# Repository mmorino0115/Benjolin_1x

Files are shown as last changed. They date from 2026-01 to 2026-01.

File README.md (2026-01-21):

# Benjolin_1x
Benjolin_1x KiCAD data. I designed this PCB based on the schematics of forestcaver's Benjolin 1.6. Then added some additional ideas from Jolin Lab's BE2N. I am really grateful to Rob Hordijk, who designed the original Benjolin. Following the original Benjolin design intent, this PCB is for personal, non-commercial use only.

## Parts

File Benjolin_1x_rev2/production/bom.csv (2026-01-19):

Designator | Footprint | Quantity | Value | LCSC Part #
C1, C2 | CP_Elec_5x4.5 | 2 | 47u
C10, C11, C12, C13, C14, C15, C16, C18, C19, C20, C21, C22, C23, C24, C25, C26, C28, C3, C4, C6, C7, C8, C9 | 0603 | 23 | 100n
C17, C5 | CP_Elec_4x5.4 | 2 | 10u
C27, C38 | 0603 | 2 | 1n
C29, C36, C37, C39 | 0603 | 4 | 560p
C30, C33, C34 | 0603 | 3 | 220p
C31, C32, C35 | 0603 | 3 | 18p
D1, D2, D6 | SOD-123 | 3 | 1N5819 | 1N5819
D10, D11, D18, D19, D22, D23, D24, D25, D26, D7, D8 | D_SOD-123F | 11 | 1N4148W-7
D12, D13, D14 | D_MiniMELF_Handsoldering | 3 | D_Zener 5V6
D15, D16, D17, D28, D5 | LED_D3.0mm | 5 | LED
D20, D21, D3, D9 | D_SMA | 4 | D_Schottky
D27, D4 | D_SMA_Handsoldering | 2 | 1n4004
FB1, FB2 | 0603 | 2 | FerriteBead
IC10 | SOT-89-3 | 1 | lm79l09
IC2 | TO-252-3 | 1 | lm78l09
J1, J10, J11, J12, J13, J14, J15, J16, J17, J2, J3, J35, J4, J5, J6, J7, J8, J9 | AudioJack_3.5mm | 18 | PJ301
JP1 | IDC-Header_2x05_P2.54mm_Vertical | 1 | M05X2PTH
POT1, POT10, POT11, POT12, POT13, POT14, POT15, POT2, POT3, POT4, POT5, POT7, POT8, POT9 | Potentiometer_Alps_RK09K_Single_Vertical | 14 | 10k
Q1, Q2, Q3, Q4, Q5, Q6 | SOT-23-3 | 6 | 2n3904
R1, R176, R18, R23, R27, R28, R29, R30, R32, R33, R49, R67, R71, R82, R86, R88 | 0603 | 16 | 10k
R10, R15, R20, R21, R22, R31, R34, R48, R52, R53, R54, R63, R65, R68, R76 | 0603 | 15 | 100k
R11 | 0603 | 1 | 62k
R12, R13, R26, R4, R41, R45, R47, R5, R51, R56, R57, R6, R66, R69, R7, R74, R8 | 0603 | 17 | 30k
R14, R16, R17, R171, R19, R24, R25, R35, R36, R37, R38, R43, R46, R77, R79, R83, R84, R87, R89, R9 | 0603 | 20 | 1k
R175 | 0603 | 1 | 7.5k
R179 | 0603 | 1 | 47k
R2, R3, R40, R59, R73 | 0603 | 5 | 15k
R39, R44, R55, R70, R72, R75, R80, R81, R85 | 0603 | 9 | 51k
R42, R58, R60, R78 | 0603 | 4 | 510
R50 | 0603 | 1 | 470k
R61 | 0603 | 1 | 20k
R62 | 0603 | 1 | 150k
R64 | 0603 | 1 | 1.5k
SW1, SW2, SW3 | 2MS3T1B3M2QES | 3 | submini-2T
U1, U5, U6 | TSSOP-14_4.4x5mm_P0.65mm | 3 | TL074
U10 | SOT-23-5 | 1 | LM321
U2, U8, U9 | TSSOP-8_4.4x3mm_P0.65mm | 3 | TL072
U3 | SOIC-16_3.9x9.9mm_P1.27mm | 1 | SSI2164_Split
U4 | SOIC-16_3.9x9.9mm_P1.27mm | 1 | 4021
V9 | PerkinElmer_VTL5C | 1 | VTL5C

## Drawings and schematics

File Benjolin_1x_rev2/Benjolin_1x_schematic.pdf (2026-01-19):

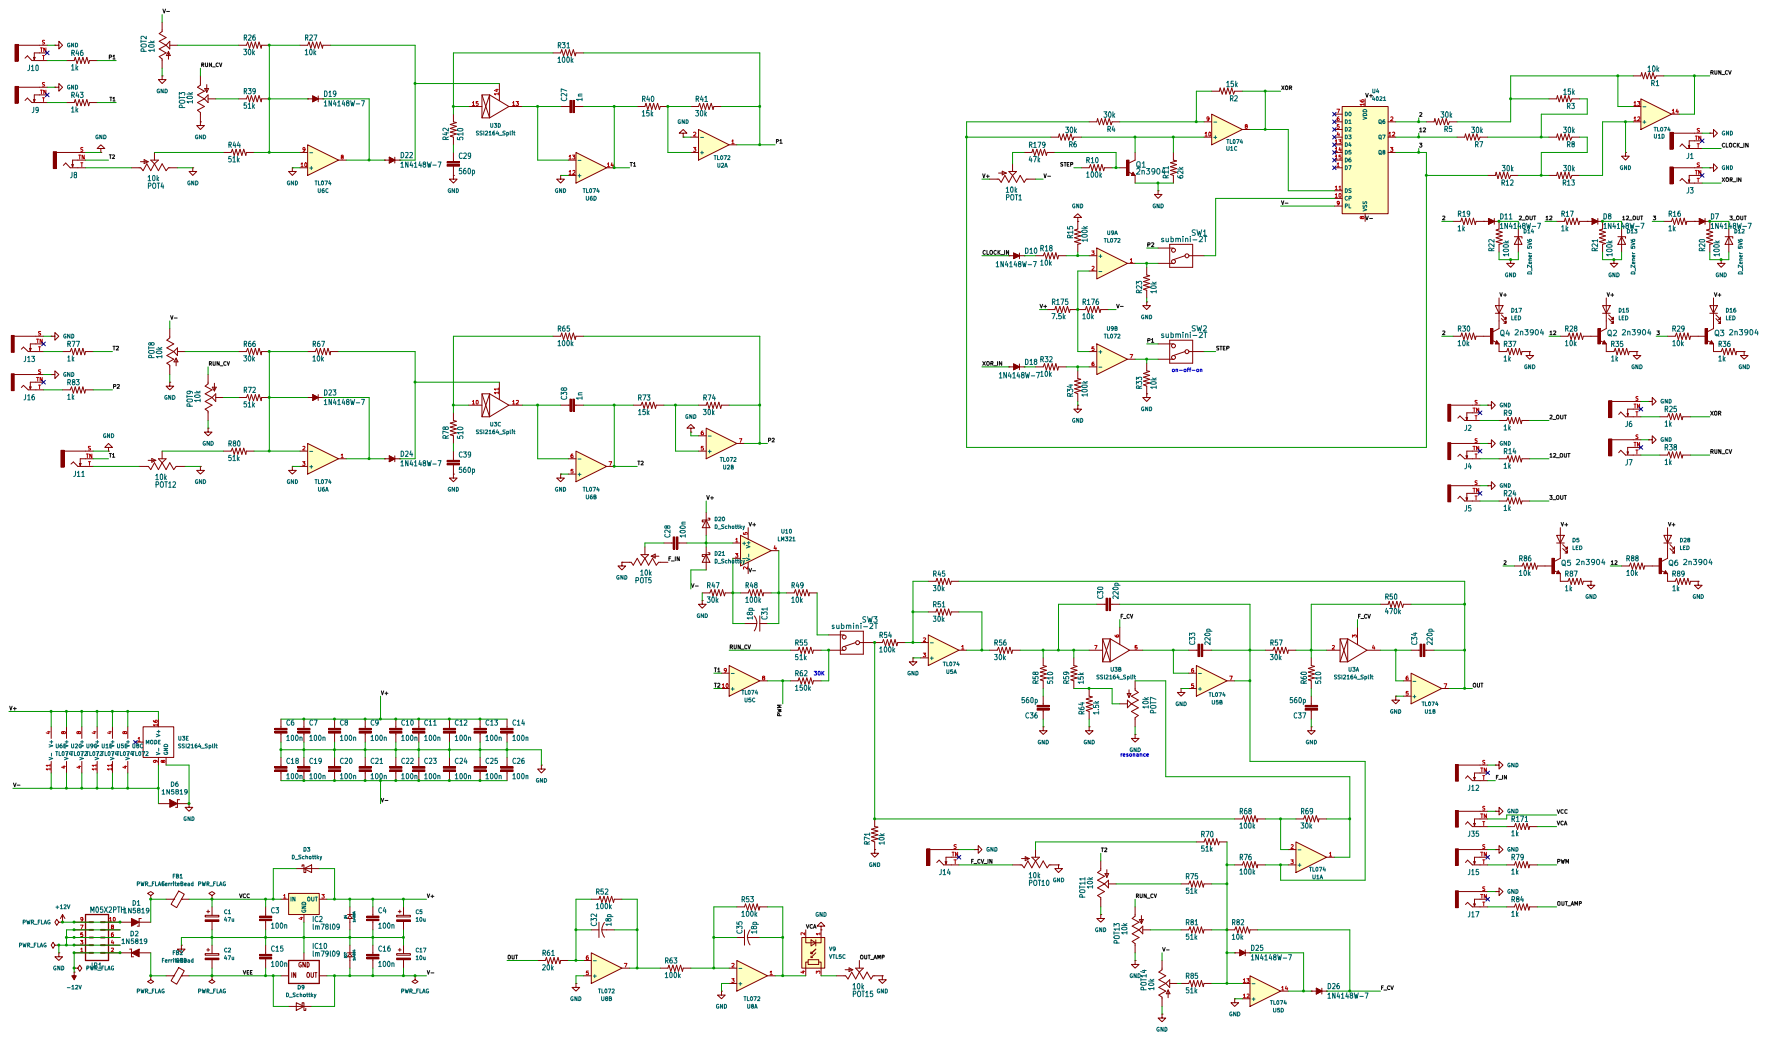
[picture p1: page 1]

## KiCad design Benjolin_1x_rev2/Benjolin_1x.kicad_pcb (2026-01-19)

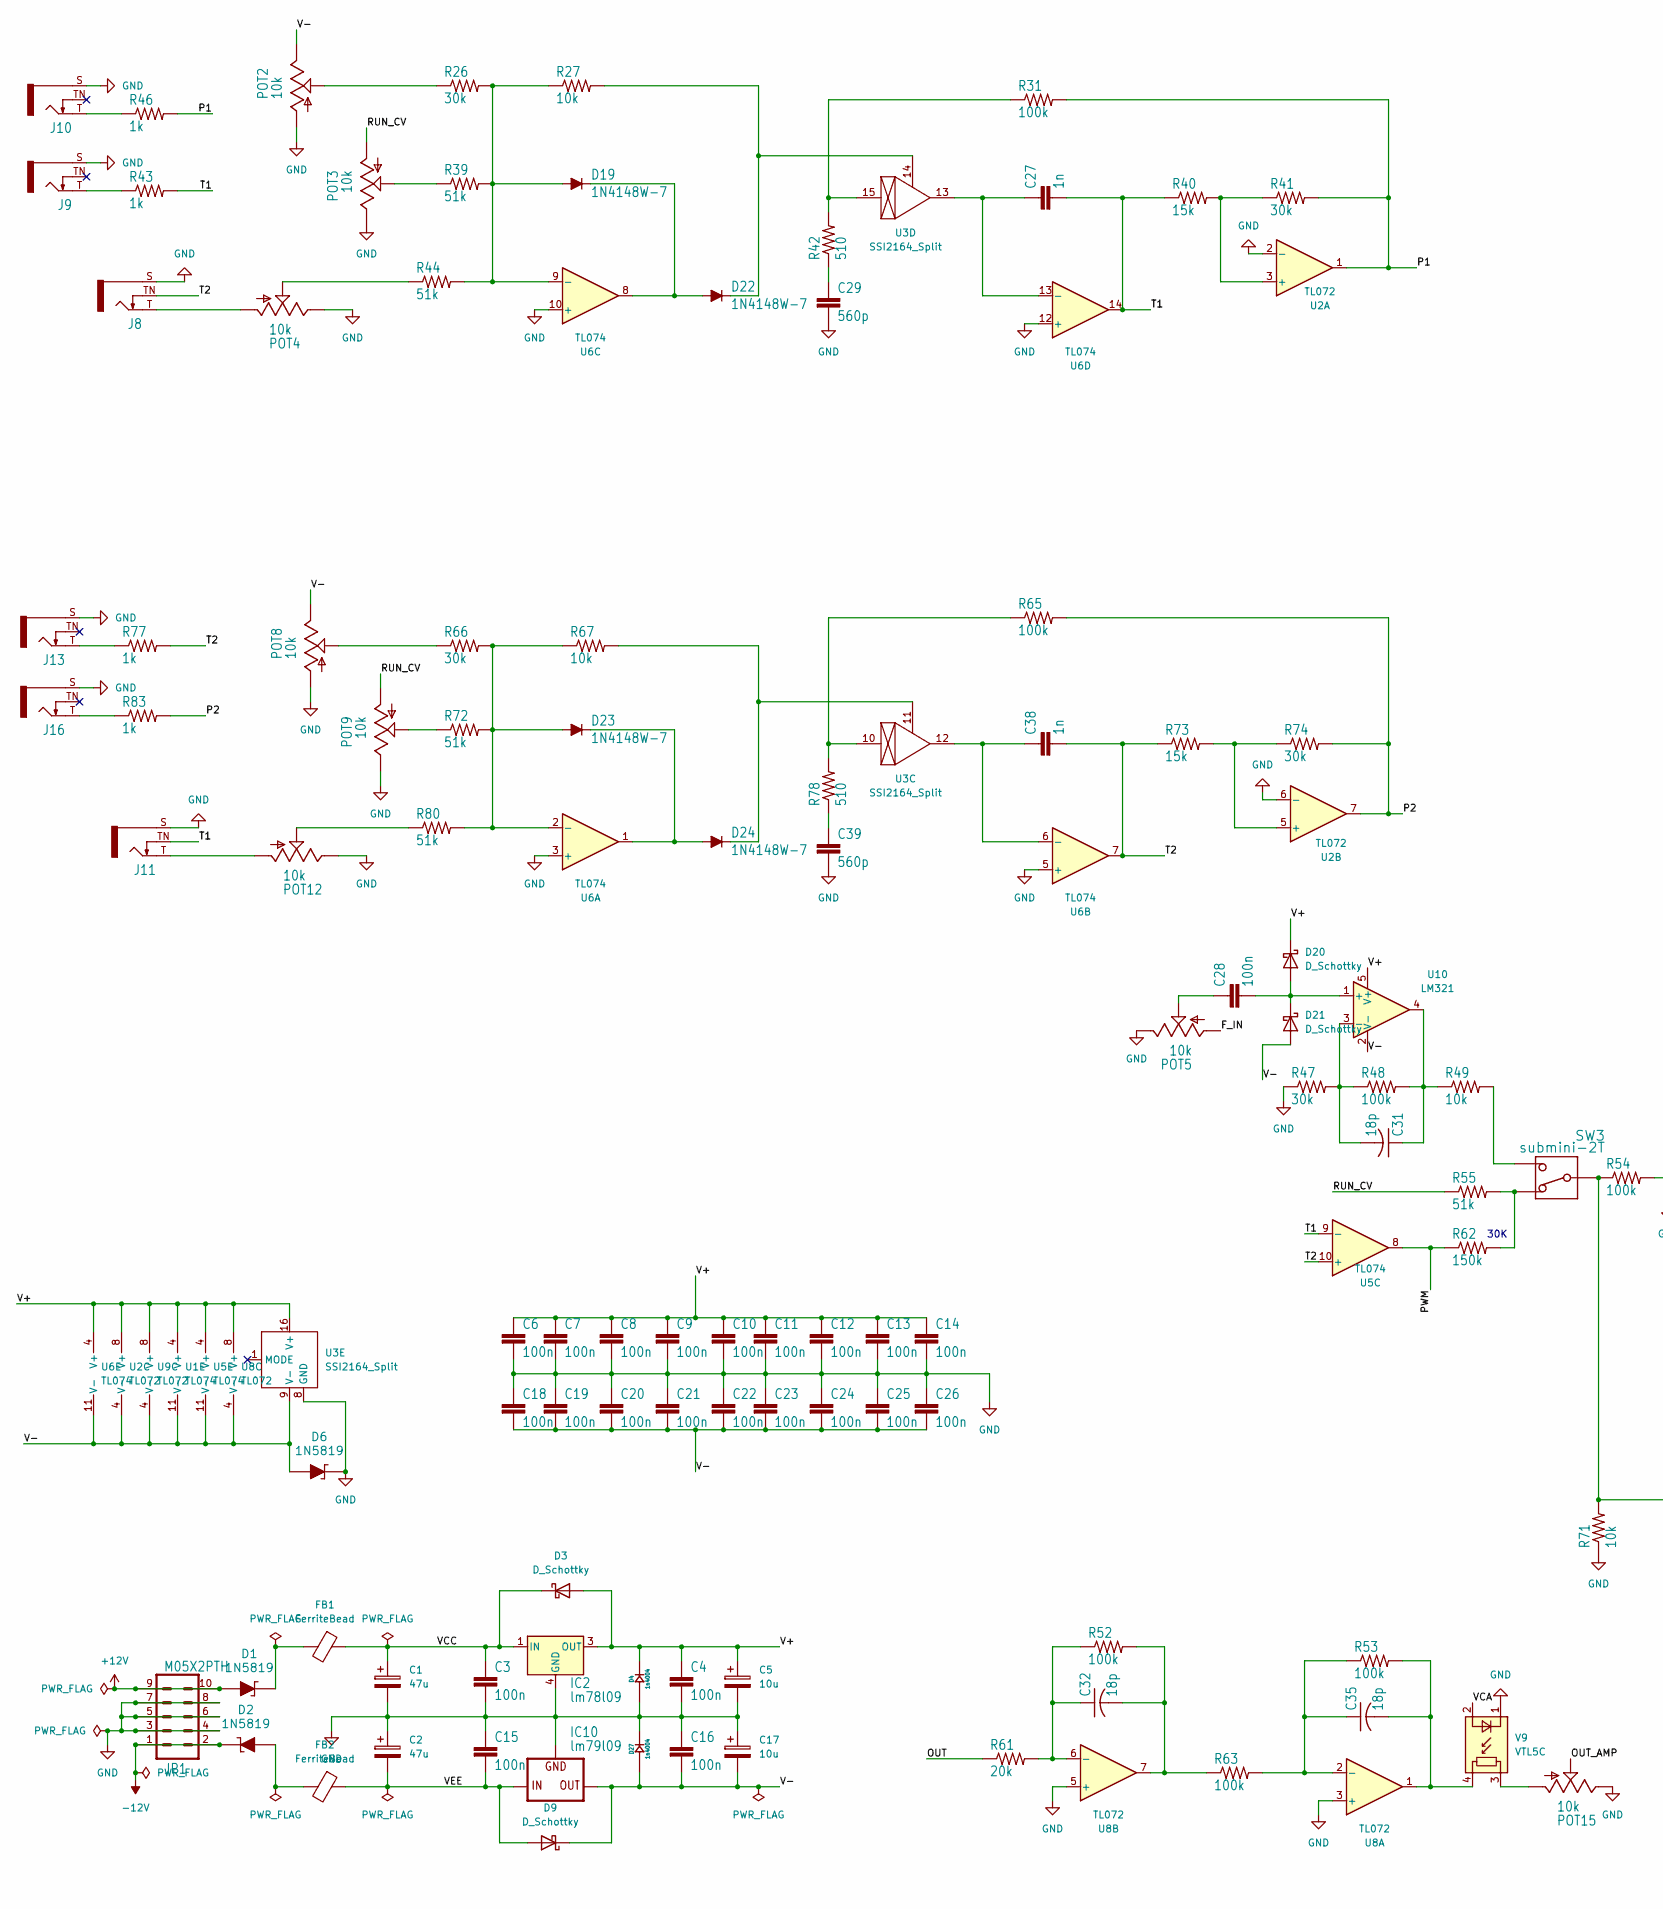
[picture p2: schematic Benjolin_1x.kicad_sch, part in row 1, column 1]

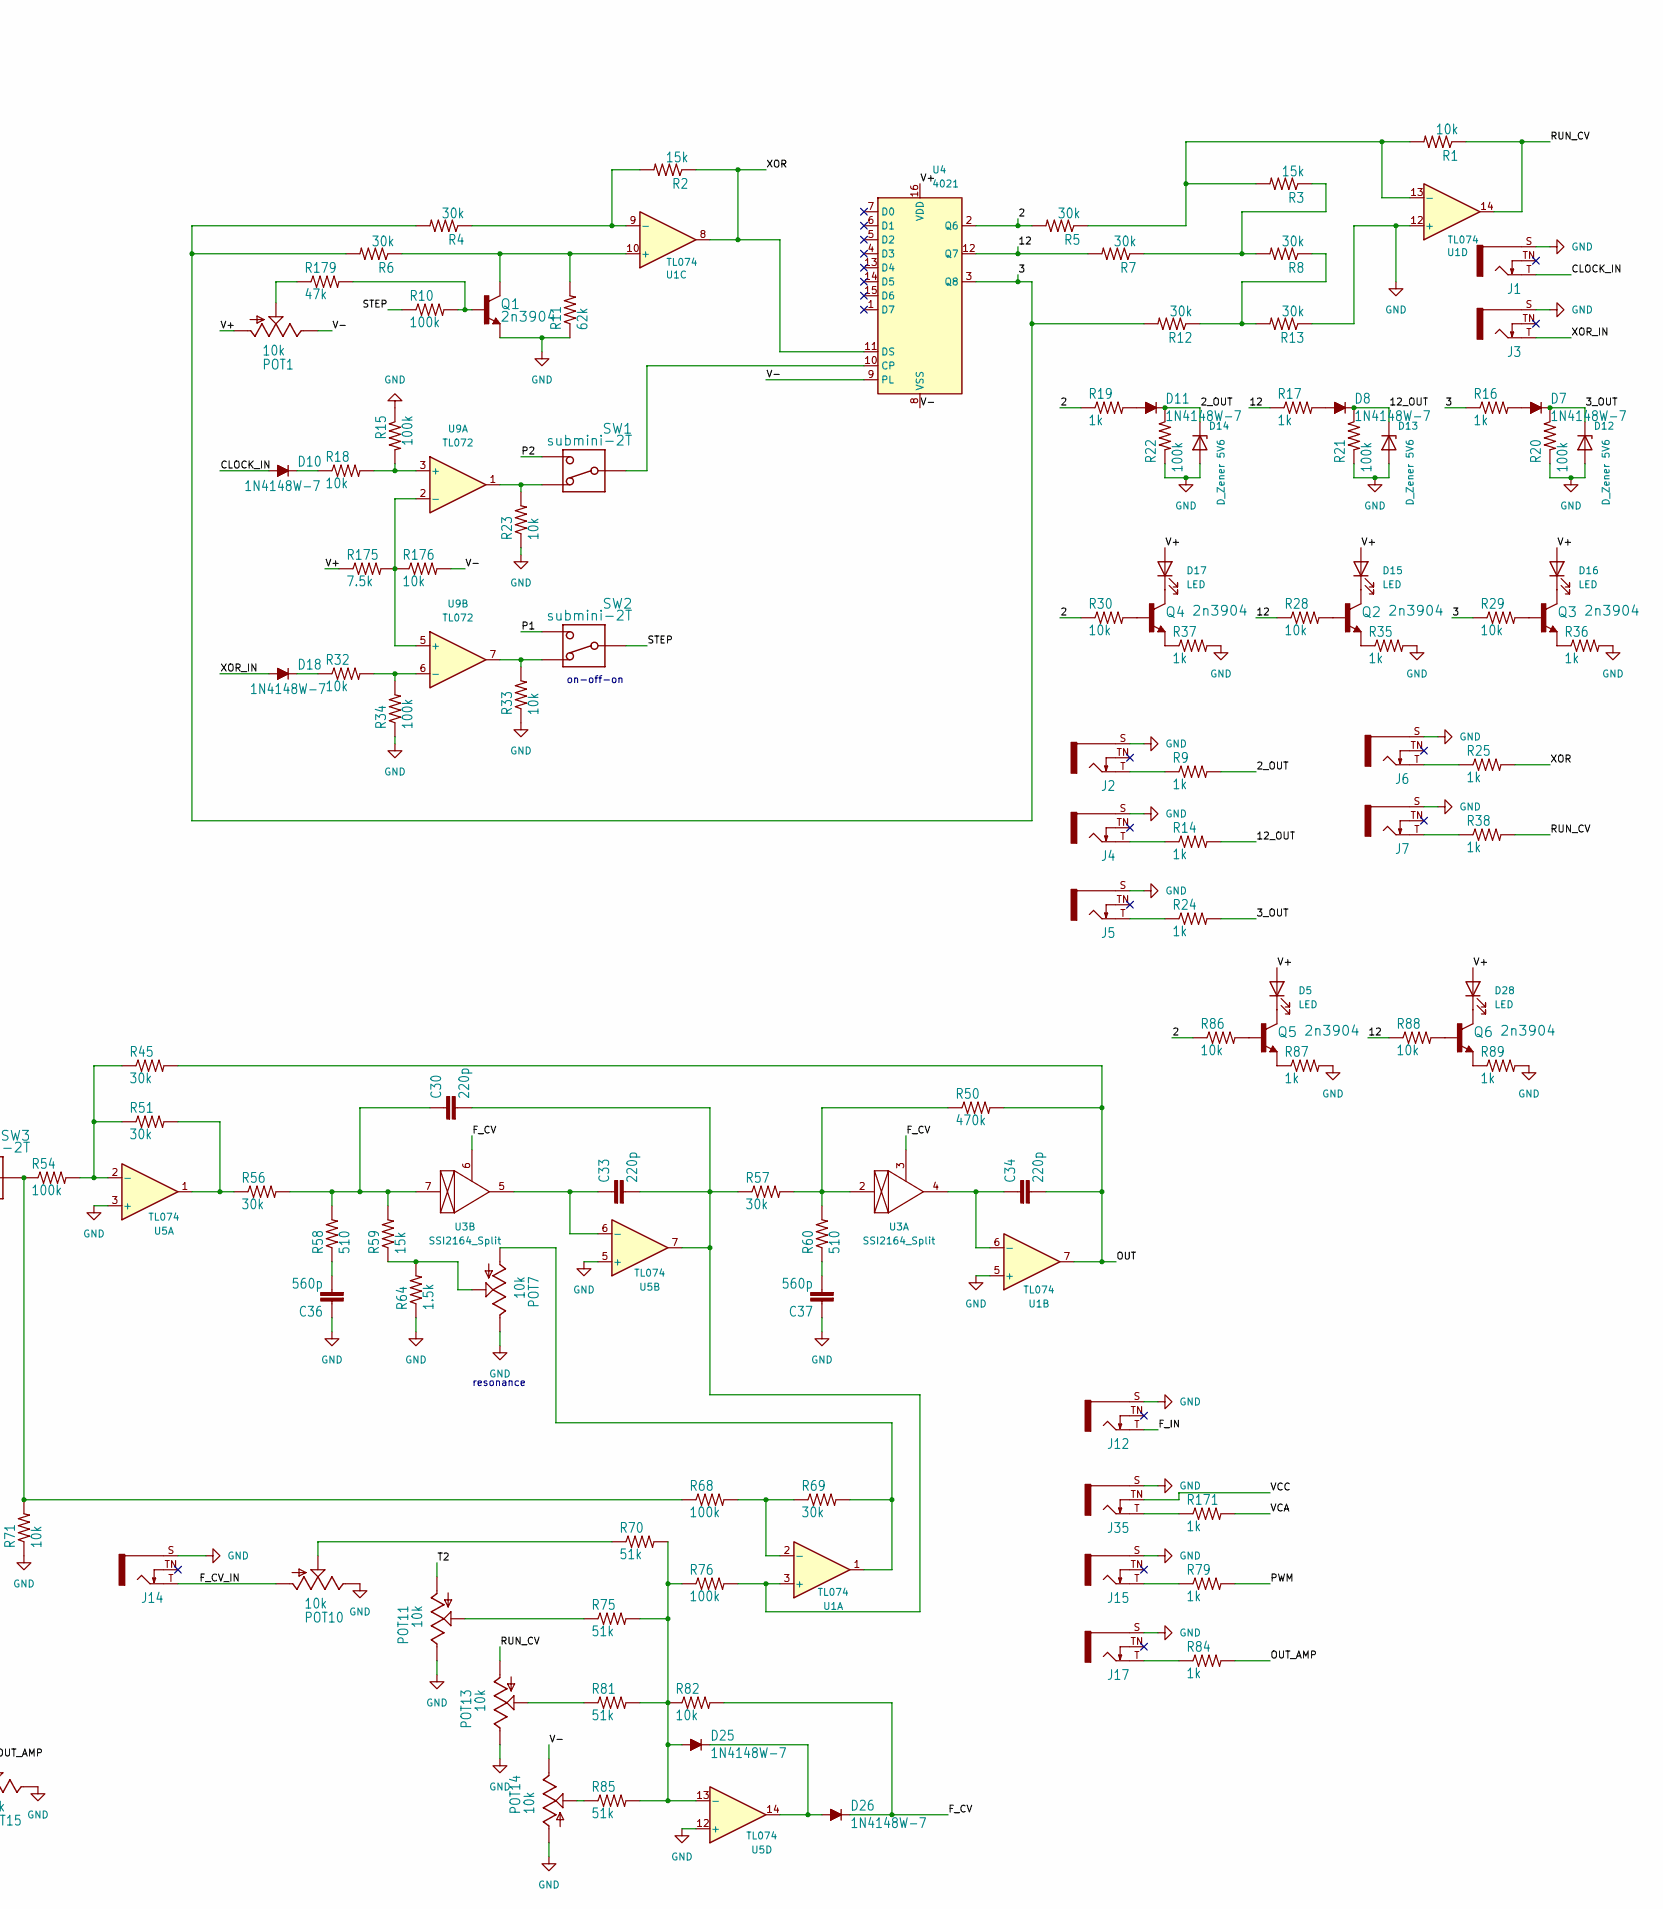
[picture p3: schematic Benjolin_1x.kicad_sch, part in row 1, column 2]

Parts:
C1, C2: 47u; CP_Elec_5x4.5
C3, C4, C6, C7, C8, C9, C10, C11, C12, C13, C14, C15, C16, C18, C19, C20, C21, C22, C23, C24, C25, C26, C28: 100n; C_0603_1608Metric_Pad1.08x0.95mm_HandSolder
C5, C17: 10u; CP_Elec_4x5.4
C27, C38: 1n; C_0603_1608Metric_Pad1.08x0.95mm_HandSolder
C29, C36, C37, C39: 560p; C_0603_1608Metric_Pad1.08x0.95mm_HandSolder
C30, C33, C34: 220p; C_0603_1608Metric_Pad1.08x0.95mm_HandSolder
C31, C32, C35: 18p; C_0603_1608Metric_Pad1.08x0.95mm_HandSolder
D1, D2, D6: 1N5819; SOD-123; MPN 1N5819; Digi-Key_PN 1N5819FSCT-ND
D3, D9, D20, D21: D_Schottky; D_SMA
D4, D27: 1n4004; D_SMA_Handsoldering
D5, D15, D16, D17, D28: LED; LED_D3.0mm
D7, D8, D10, D11, D18, D19, D22, D23, D24, D25, D26: 1N4148W-7; D_SOD-123F
D12, D13, D14: D_Zener 5V6; D_MiniMELF_Handsoldering
FB1, FB2: FerriteBead; L_0603_1608Metric
IC2: lm78l09; TO-252-3
IC10: lm79l09; SOT-89-3
J1, J2, J3, J4, J5, J6, J7, J8, J9, J10, J11, J12, J13, J14, J15, J16, J17, J35: PJ301_THONKICONN6; AudioJack_3.5mm
JP1: M05X2PTH; IDC-Header_2x05_P2.54mm_Vertical
POT1, POT2, POT3, POT4, POT5, POT7, POT8, POT9, POT10, POT11, POT12, POT13, POT14, POT15: 10k; Potentiometer_Alps_RK09K_Single_Vertical
Q1, Q2, Q3, Q4, Q5, Q6: 2n3904; SOT-23-3
R1, R18, R23, R27, R28, R29, R30, R32, R33, R49, R67, R71, R82, R86, R88, R176: 10k; R_0603_1608Metric_Pad0.98x0.95mm_HandSolder
R2, R3, R40, R59, R73: 15k; R_0603_1608Metric_Pad0.98x0.95mm_HandSolder
R4, R5, R6, R7, R8, R12, R13, R26, R41, R45, R47, R51, R56, R57, R66, R69, R74: 30k; R_0603_1608Metric_Pad0.98x0.95mm_HandSolder
R9, R14, R16, R17, R19, R24, R25, R35, R36, R37, R38, R43, R46, R77, R79, R83, R84, R87, R89, R171: 1k; R_0603_1608Metric_Pad0.98x0.95mm_HandSolder
R10, R15, R20, R21, R22, R31, R34, R48, R52, R53, R54, R63, R65, R68, R76: 100k; R_0603_1608Metric_Pad0.98x0.95mm_HandSolder
R11: 62k; R_0603_1608Metric_Pad0.98x0.95mm_HandSolder
R39, R44, R55, R70, R72, R75, R80, R81, R85: 51k; R_0603_1608Metric_Pad0.98x0.95mm_HandSolder
R42, R58, R60, R78: 510; R_0603_1608Metric_Pad0.98x0.95mm_HandSolder
R50: 470k; R_0603_1608Metric_Pad0.98x0.95mm_HandSolder
R61: 20k; R_0603_1608Metric_Pad0.98x0.95mm_HandSolder
R62: 150k; R_0603_1608Metric_Pad0.98x0.95mm_HandSolder
R64: 1.5k; R_0603_1608Metric_Pad0.98x0.95mm_HandSolder
R175: 7.5k; R_0603_1608Metric_Pad0.98x0.95mm_HandSolder
R179: 47k; R_0603_1608Metric_Pad0.98x0.95mm_HandSolder
SW1, SW2, SW3: submini-2T; SPDT
U1, U5, U6: TL074; TSSOP-14_4.4x5mm_P0.65mm
U2, U8, U9: TL072; TSSOP-8_4.4x3mm_P0.65mm
U3: SSI2164_Split; SOIC-16_3.9x9.9mm_P1.27mm
U4: 4021; SOIC-16_3.9x9.9mm_P1.27mm
U10: LM321; SOT-23-5
V9: VTL5C; PerkinElmer_VTL5C

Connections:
+12V: D1.A, JP1.9, JP1.10
-12V: D2.K, JP1.1, JP1.2
/2: R5.2, R19.1, R30.1, R86.1, U4.2 (Q6)
/2_OUT: D11.1, D14.1 (K), R9.2, R22.1
/3: R4.2, R6.2, R12.2, R16.1, R29.1, U4.3 (Q8)
/3_OUT: D7.1, D12.1 (K), R20.1, R24.2
/12: R7.2, R17.1, R28.1, R88.1, U4.12 (Q7)
/12_OUT: D8.1, D13.1 (K), R14.2, R21.1
/CLOCK_IN: D10.2, J1.T
/F_CV: D26.1, R82.2, U3.3, U3.6
/F_CV_IN: J14.T, POT10.3
/F_IN: J12.T, POT5.3
/OUT: C34.2, R45.2, R50.2, R61.1, U1.7
/OUT_AMP: POT15.2, R84.2
/P1: R31.2, R41.2, R46.2, SW2.1, U2.1
/P2: R65.2, R74.2, R83.2, SW1.1, U2.7
/PWM: R62.1, R79.2, U5.8
/RUN_CV: POT3.3, POT9.3, POT13.3, R1.1, R38.2, R55.1, U1.14
/STEP: R10.1, SW2.2
/T1: C27.2, J11.TN, R40.1, R43.2, U5.9 (-), U6.14
/T2: C38.2, J8.TN, POT11.3, R73.1, R77.2, U5.10 (+), U6.7
/V+: C4.1, C5.1, C6.1, C7.1, C8.1, C9.1, C10.1, C11.1, C12.1, C13.1, C14.1, D3.2 (A), D4.2 (-), D5.2 (A), D15.2 (A), D16.2 (A), D17.2 (A), D20.1 (K), D28.2 (A), IC2.3 (OUT), POT1.3, R175.1, U1.4 (V+), U2.8 (V+), U3.16 (V+), U4.16 (VDD), U5.4 (V+), U6.4 (V+), U8.8 (V+), U9.8 (V+), U10.5 (V+)
/V-: C16.2, C17.2, C18.2, C19.2, C20.2, C21.2, C22.2, C23.2, C24.2, C25.2, C26.2, D6.A, D9.1 (K), D21.2 (A), D27.1 (+), IC10.3 (OUT), POT1.1, POT2.1, POT8.1, POT14.1, R176.2, U1.11 (V-), U2.4 (V-), U3.9 (V-), U4.8 (VSS), U4.9 (PL), U5.11 (V-), U6.11 (V-), U8.4 (V-), U9.4 (V-), U10.2 (V-)
/VCA: R171.2, V9.2 (+)
/VCC: C1.1, C3.1, D3.1 (K), FB1.1, IC2.1 (IN), J35.TN
/VEE: C2.2, C15.2, D9.2 (A), FB2.1, IC10.2
/XOR: R2.1, R25.2, U1.8, U4.11 (DS)
/XOR_IN: D18.2, J3.T
GND: C1.2, C2.1, C3.2, C4.2, C5.2, C6.2, C7.2, C8.2, C9.2, C10.2, C11.2, C12.2, C13.2, C14.2, C15.1, C16.1, C17.1, C18.1, C19.1, C20.1, C21.1, C22.1, C23.1, C24.1, C25.1, C26.1, C29.2, C36.1, C37.1, C39.2, D4.1 (+), D6.K, D12.2 (A), D13.2 (A), D14.2 (A), D27.2 (-), IC2.4 (GND), IC10.1 (GND), J1.S, J2.S, J3.S, J4.S, J5.S, J6.S, J7.S, J8.S, J9.S, J10.S, J11.S, J12.S, J13.S, J14.S, J15.S, J16.S, J17.S, J35.S, JP1.3, JP1.4, JP1.5, JP1.6, JP1.7, JP1.8, POT2.3, POT3.1, POT4.1, POT5.1, POT7.1, POT8.3, POT9.1, POT10.1, POT11.1, POT12.1, POT13.1, POT14.3, POT15.1, Q1.2 (E), R11.1, R13.1, R15.1, R20.2, R21.2, R22.2, R23.1, R33.1, R34.1, R35.2, R36.2, R37.2, R47.1, R64.1, R71.1, R87.2, R89.2, U1.5 (+), U1.12 (+), U2.2 (-), U2.6 (-), U3.8 (GND), U5.3 (+), U5.5 (+), U5.12 (+), U6.3 (+), U6.5 (+), U6.10 (+), U6.12 (+), U8.3 (+), U8.5 (+), V9.1 (-)
unnamed: C28.1, POT5.2
unnamed: C29.1, R42.1
unnamed: C30.1, R56.2, R58.2, R59.2, U3.7
unnamed: C31.1, R48.2, R49.1, U10.4
unnamed: C32.2, R52.2, R63.1, U8.7
unnamed: C35.2, R53.2, U8.1, V9.4
unnamed: C36.2, R58.1
unnamed: C37.2, R60.1
unnamed: C39.1, R78.1
unnamed: D1.K, FB1.2
unnamed: D2.A, FB2.2
unnamed: D5.1 (K), Q5.3 (C)
unnamed: D7.2, R16.2
unnamed: D8.2, R17.2
unnamed: D10.1, R18.1
unnamed: D11.2, R19.2
unnamed: D15.1 (K), Q2.3 (C)
unnamed: D16.1 (K), Q3.3 (C)
unnamed: D17.1 (K), Q4.3 (C)
unnamed: D18.1, R32.1
unnamed: D19.1, D22.2, U6.8
unnamed: C28.2, D20.2 (A), D21.1 (K), U10.1 (+)
unnamed: D22.1, R27.2, U3.14
unnamed: D23.1, D24.2, U6.1
unnamed: D24.1, R67.2, U3.11
unnamed: D25.1, D26.2, U5.14
unnamed: D28.1 (K), Q6.3 (C)
unnamed: J2.T, R9.1
unnamed: J4.T, R14.1
unnamed: J5.T, R24.1
unnamed: J6.T, R25.1
unnamed: J7.T, R38.1
unnamed: J8.T, POT4.3
unnamed: J9.T, R43.1
unnamed: J10.T, R46.1
unnamed: J11.T, POT12.3
unnamed: J13.T, R77.1
unnamed: J15.T, R79.1
unnamed: J16.T, R83.1
unnamed: J17.T, R84.1
unnamed: J35.T, R171.1
unnamed: POT1.2, R179.1
unnamed: POT2.2, R26.1
unnamed: POT3.2, R39.1
unnamed: POT4.2, R44.1
unnamed: POT7.2, R59.1, R64.2
unnamed: POT7.3, R69.2, U1.1
unnamed: POT8.2, R66.1
unnamed: POT9.2, R72.1
unnamed: POT10.2, R70.1
unnamed: POT11.2, R75.1
unnamed: POT12.2, R80.1
unnamed: POT13.2, R81.1
unnamed: POT14.2, R85.1
unnamed: POT15.3, V9.3
unnamed: Q1.1 (B), R10.2, R179.2
unnamed: Q1.3 (C), R6.1, R11.2, U1.10 (+)
unnamed: Q2.1 (B), R28.2
unnamed: Q2.2 (E), R35.1
unnamed: Q3.1 (B), R29.2
unnamed: Q3.2 (E), R36.1
unnamed: Q4.1 (B), R30.2
unnamed: Q4.2 (E), R37.1
unnamed: Q5.1 (B), R86.2
unnamed: Q5.2 (E), R87.1
unnamed: Q6.1 (B), R88.2
unnamed: Q6.2 (E), R89.1
unnamed: R3.1, R7.1, R8.2
unnamed: R8.1, R12.1, R13.2
unnamed: R23.2, SW1.3, U9.1
unnamed: R31.1, R42.2, U3.15
unnamed: R33.2, SW2.3, U9.7
unnamed: R49.2, SW3.1
unnamed: R50.1, R57.2, R60.2, U3.2
unnamed: R51.2, R56.1, U5.1
unnamed: R54.1, R68.1, R71.2, SW3.2
unnamed: R55.2, R62.2, SW3.3
unnamed: R65.1, R78.2, U3.10
unnamed: C30.2, C33.2, R57.1, R76.2, U1.3 (+), U5.7
unnamed: R68.2, R69.1, U1.2 (-)
unnamed: C34.1, U1.6 (-), U3.4
unnamed: R2.2, R4.1, U1.9 (-)
unnamed: R1.2, R3.2, R5.1, U1.13 (-)
unnamed: R40.2, R41.1, U2.3 (+)
unnamed: R73.2, R74.1, U2.5 (+)
unnamed: SW1.2, U4.10 (CP)
unnamed: R45.1, R51.1, R54.2, U5.2 (-)
unnamed: C33.1, U3.5, U5.6 (-)
unnamed: D25.2, R70.2, R75.2, R76.1, R81.2, R82.1, R85.2, U5.13 (-)
unnamed: D23.2, R66.2, R67.1, R72.2, R80.2, U6.2 (-)
unnamed: C38.1, U3.12, U6.6 (-)
unnamed: D19.2, R26.2, R27.1, R39.2, R44.2, U6.9 (-)
unnamed: C27.1, U3.13, U6.13 (-)
unnamed: C35.1, R53.1, R63.2, U8.2 (-)
unnamed: C32.1, R52.1, R61.2, U8.6 (-)
unnamed: R15.2, R18.2, U9.3 (+)
unnamed: R175.2, R176.1, U9.2 (-), U9.5 (+)
unnamed: R32.2, R34.2, U9.6 (-)
unnamed: C31.2, R47.2, R48.1, U10.3 (-)

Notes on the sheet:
on-off-on
resonance
30K

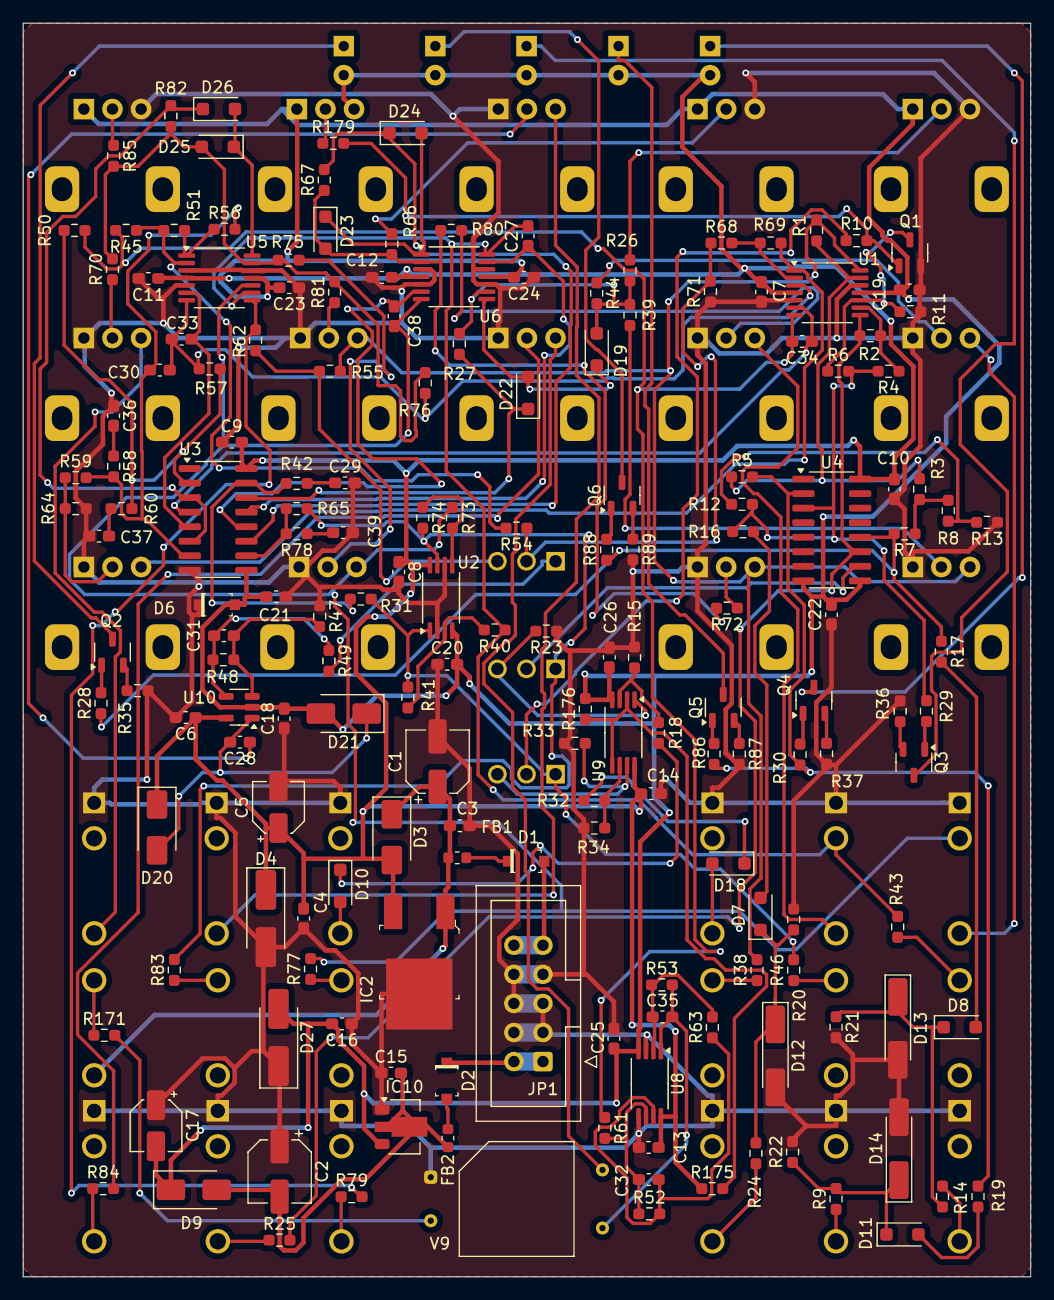
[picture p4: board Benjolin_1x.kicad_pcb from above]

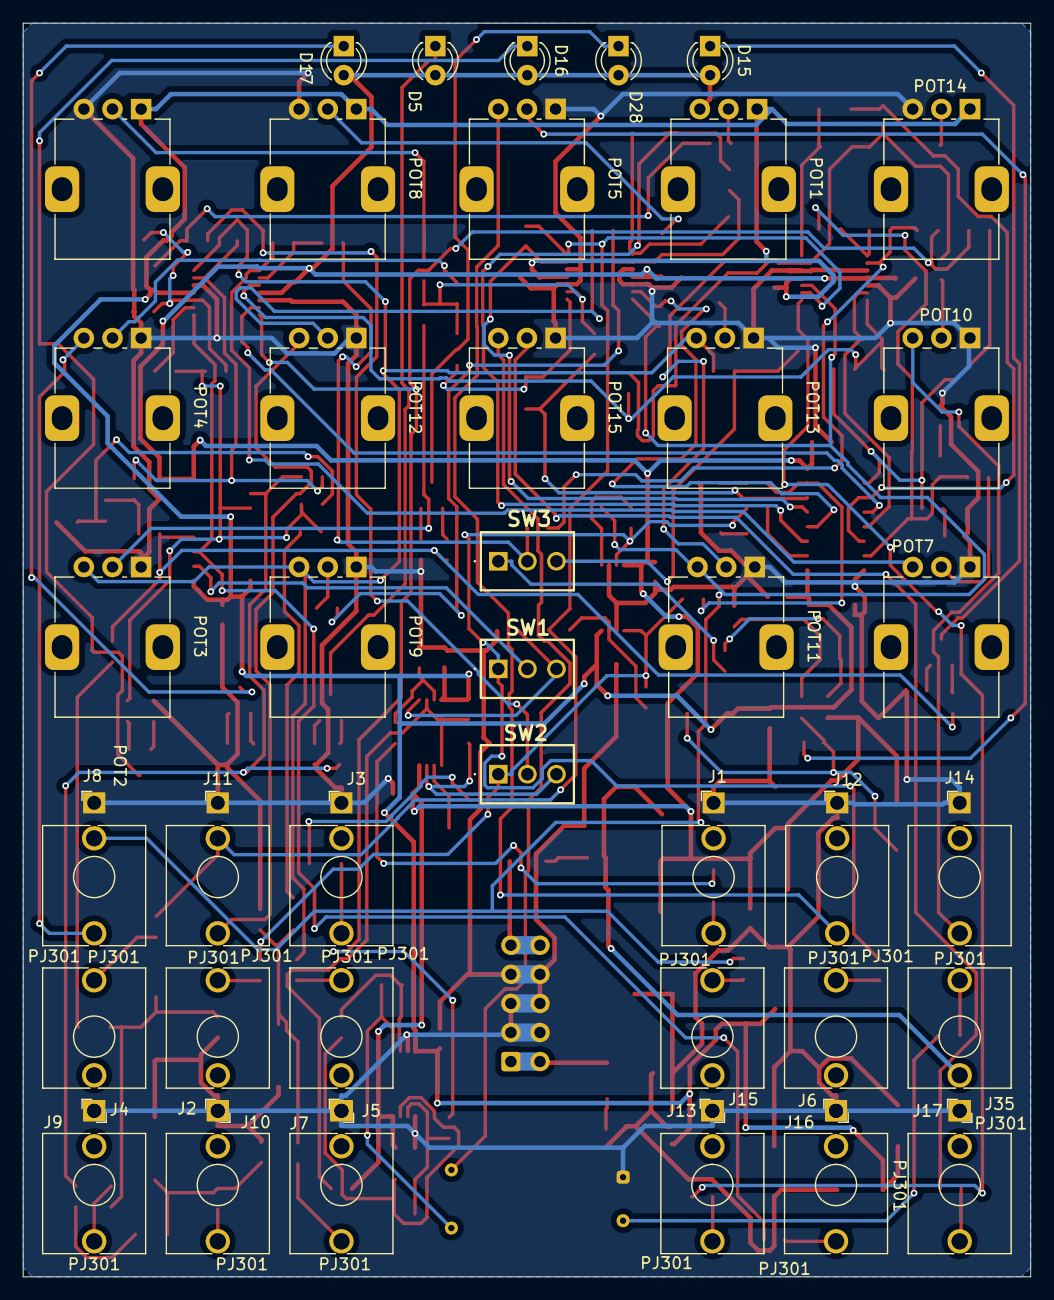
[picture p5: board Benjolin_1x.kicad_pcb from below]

Board: 2 copper layers, 88.0 x 109.5 mm, 216 parts (40 on the bottom side), 128 nets.
